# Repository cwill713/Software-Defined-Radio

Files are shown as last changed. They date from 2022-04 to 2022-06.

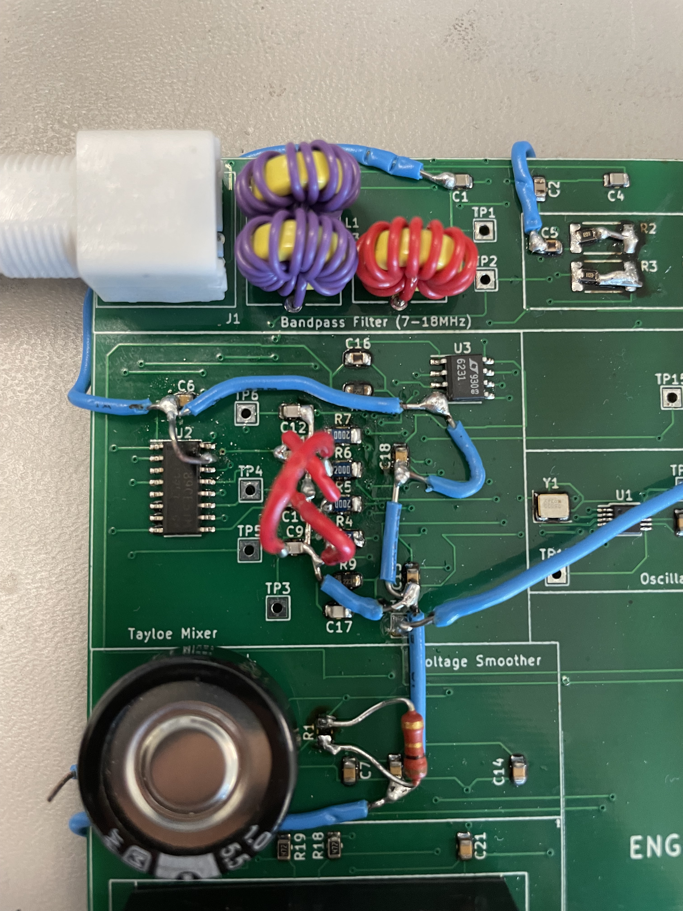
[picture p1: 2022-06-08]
Pictures/Josh's Fixed Board image 2.jpg

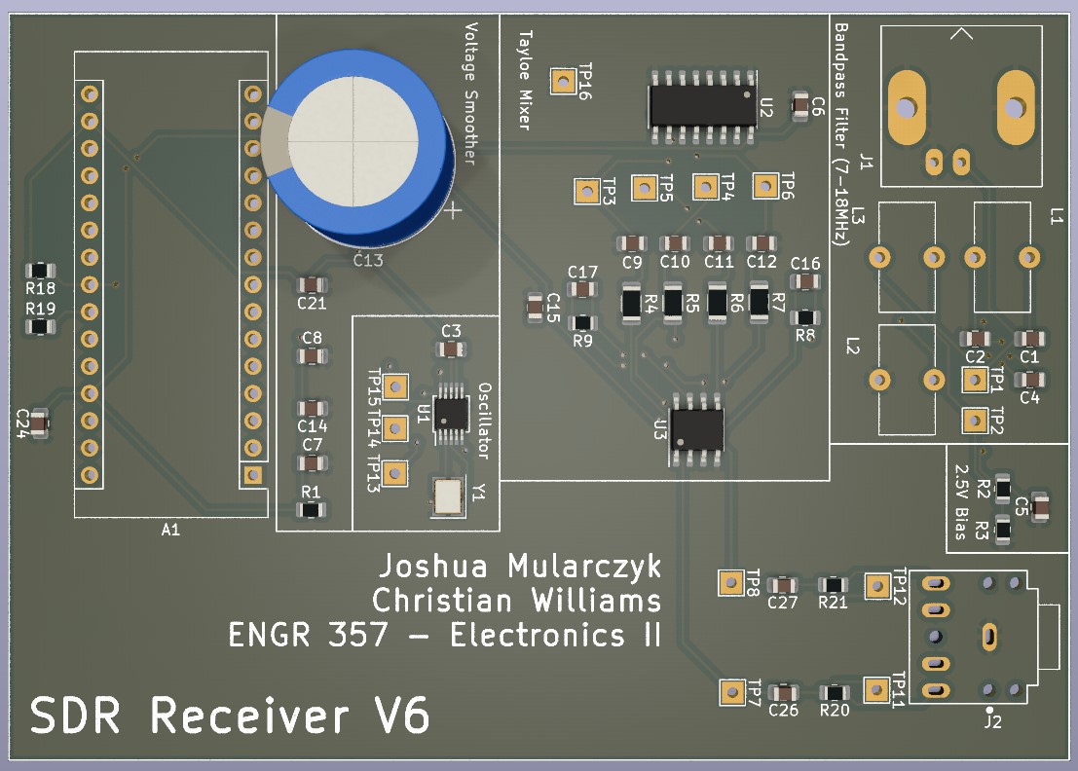
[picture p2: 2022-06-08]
Pictures/V6 Circuit Board.jpg

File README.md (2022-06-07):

# Software-Defined-Radio-Reciever
This project, assigned to us by [Dr. Frohne](https://github.com/frohro), combines our professors' interest HAM radio and a practical application of gain, opamp analysis, noise, and AC/DC analysis that we learned in Electronics I. This is the design of Software Defined Radio built in collaboration with [Joshua Mularczyk](https://github.com/JoshuaMularczyk) for our Engineering Electronics II class.

## Design Specifications
When perfroming research for this project, Joshua and I began to figure out what specifations our SDR would follow. Origianlly, we wanted to build a commercial FM radio, but after discusstion with Dr. Frohne, we reconsidered. The final specifications we decided on are as follows:
- Frequency Range: 7MHZ - 18MHz
- Radio Type: Shortwave
- Inexpensive
- Low Noise Figure
- -107 dBm (1uV) Minimum Discernable Signal
- Good Image Rejection

The subcirucits used to create this SDR are: 
- Butterworth Bandpass Filter
- Tayloe Mixer
- Bessel Lowpass Filter
- Power Supply Noise Filter
- 2.5V Voltage Bias
- Arduino Controlled Oscillator

## Theory



This block diagram shows an overveir of how a Software Defined Radio works. A signal is recieved from the antenna and then passes through the band pass filter. Here all desired frequencies are let through and the others discarded. Then the signals are passed through the Tayloe Mmixer where the signal is then split into four new ones that are 90 degrees out of phase. The these signals, the sets that are 180 degrees apart, are combined in a set of opamps that double as lowpass filters to ensure the output signal has a frequency no greater than 100kHz. These new two signals are then passed through the sound card to the system running the [Quisk](https://james.ahlstrom.name/quisk/) software which allows us to hear what is being transmitted on the signal and change the signal taht we are listening to. The Arduino Nano and the Si5351 that runs a [program](https://github.com/cwill713/Software-Defined-Radio/tree/main/Arduino%20Code/New_Quisk_Nano) that allows it to act as our oscillator that can be changed by what ever frequency Quisk is trying to demodulate.

## Schematics
The following are the initial schematics that Joshua and I have designed for the SDR.

### BandPass Filter
BandPass Filter and Voltage Divider
We built this bandpass filter using the [LC Filter Design Tool](https://rf-tools.com/lc-filter/). This is a Butterworth Filter that will only allow frequencies between 8MHz and 18MHz to pass through it.

The voltage divider will take our Filtered 5V and output a 2.5 DC voltage to drive the rest of the circuit. 

### Mixer and Lowpass Filter
Tayloe Mixer
The mixer that Joshua and I decided to use was  Tayloe Mixer. The Tayloe mixer uses switches to combined the signals that are 180 degrees out of phase with differential amplifiers so that signals above and below the oscilator frequecy can be detected.

The lowpass filter will block all frequencies greater that 100kHz.

### Voltage Smoother
Voltage Smoother

The Voltage Smoother with take the 5V Vcc and remove as much noise as possible that comes in from the computer and outputs a smoother 5V for the SDR to use.

### Arduino and Si5351
Arduino and Si5351

The Si5351 programmable oscillator will allow us to input two clock signals that are 90 degrees out of phase into S0 and S1 of the SN74CBT3253. The Arduino Nano will control the frequency the is put out by the Si5351 for tuning.

## Simulations
The following are the simulations of our filters and our SDR as a whole.

### Bandpass Filter
Bandpass Filter Simulation Graph
Bandpass Filter Simulation

As seen above, the bandpass fitler we designed, as a start band of 7MHz and a stop band of 18MHz.

### Lowpass Filter
LowPass Filter Simulation
LowPass Filter Schematic
After the the I and Q signals from the 2N74CBT3253 are combined in the LT6231 opamps we can see that no frequencies above 100kHz are allowed through.

### Complete SDR
Complete Simulation Graph
Complete SDR Simulation

We simulated our complete SDR the combined bandpass simulation, our tayloe mixer, simulated by using four voltage controlled switches the produced 4 pusles that are 90 degrees out of phase, and our lowpass filter simulation. You can see the two outputs are the baseband I and Q output signals that are 90 degrees out of phase.

## Rev 5 PCB Design and Testing
My partner and I each designed our own version of our board, but my partner had the better board layout. So we used his [V5](https://github.com/cwill713/Software-Defined-Radio/tree/main/Schematic%20Files/SDRrecV5) of our schematic, PCB, and drill files and sent them to our professor who sent our files to [JLPCB](https://jlcpcb.com/VGS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) for printing. We then ordered that parts needed then constructed and tested our board. 

Our V5 Circuit Board PCB

### Initial Testing
During the initial testing, a fellow student, [Nicholas Zimmerman](https://github.com/nickz12345), found that we had a wiring issue in our mixer. To fix this issue on my board, I cut the traces on my board and corrected the mistakes with jumper wires. Jumping one of these traces, I made a mistake and broked one of the capacitors, its pad, and the trace to one of the test points. Due to the lack of time to complete the project, Josh and I used his board for our final testing.

We also found that our boards were missing our ground plan, due to it being temporarily turned off when the gerber files were generated. To fix this I manually wired all the grounds to the ground on the BNC connector.

The last mistake we had was in the second lowpass filter. When had the the second set of opamps running between Vcc and ground instead of Vcc and -Vcc. Because of this, this set of opamps had enough gain that they became saturated. Luckily for us, this second lowpass filter was a back up for the first. We decided to bypass the second lowpass filter because the output signal from the first lowpass filter was exactly what we needed.

The images of our boards can be seen [here](https://github.com/cwill713/Software-Defined-Radio/tree/main/Pictures).

### V6 PCB Design
V6 Circuit Board
After fixing these mistakes on the board, I fixed these issues in the [V6](https://github.com/cwill713/Software-Defined-Radio/tree/main/Schematic%20Files/SDRrecV6) KiCAD files.

## Project Resuslts
### Minimum Discenable Signal
When testing to see the minimum discernible signal we connected our board up to our signal generator, our system running quisk software, and our soundcard. We adjusted the attenuator on the signal generator to output a signal of 14.19MHz and adjusted the attenuator to see how small of a signal we could detect. In the image below, we see our radio discern a signal of .35uV!
minDecV2

### Practical Test
Next, we decided to see if we could find any bandwidths where people were talking and try to listen in. To do this, we disconnected the board from the signal generator and connected our board to the antenna of our building. Scanning the differnt frequencies we found two bandwidths being used for communications.

The first was being used to communicate the weather from what we are assuming to be an air traffic control tower. 

weather
"Wind 360 degrees, light drizzle, visibility more than 6 miles".

The second bandwidth was being used as an automated message that repeated the time once a minute.
listeningIn
"At the tone ***** _5 hours 52 minutes coordinated universal time"

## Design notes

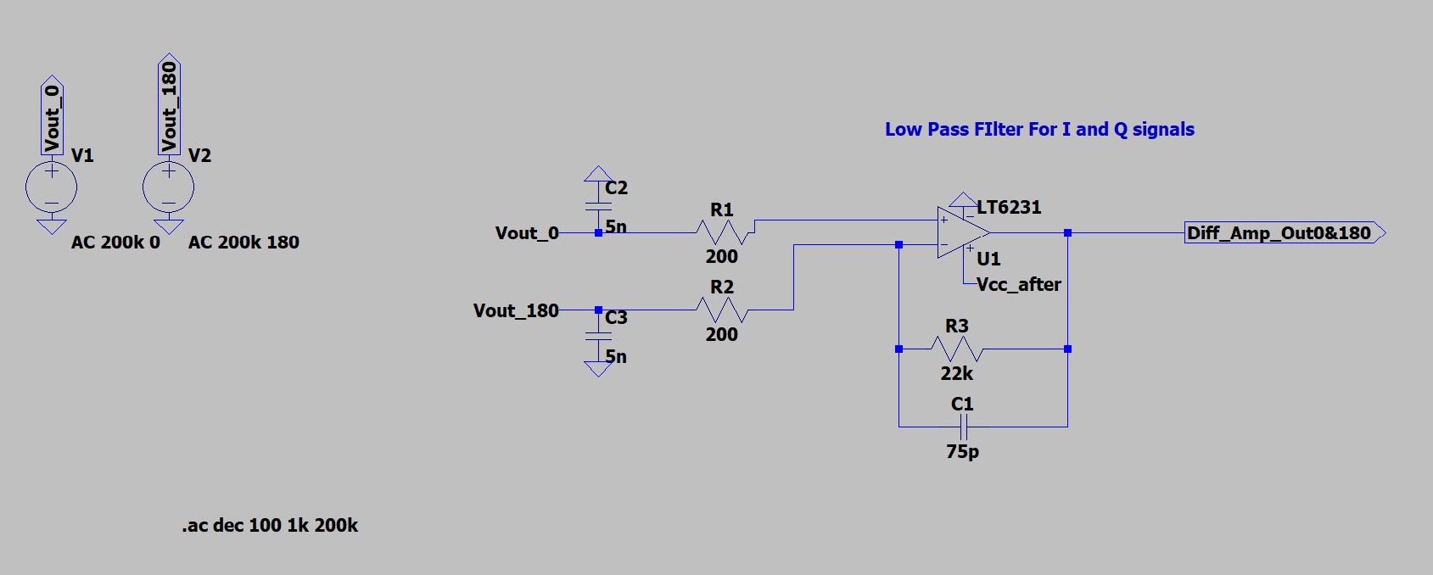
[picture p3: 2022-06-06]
Pictures/LowPass Filter Schematic.jpg

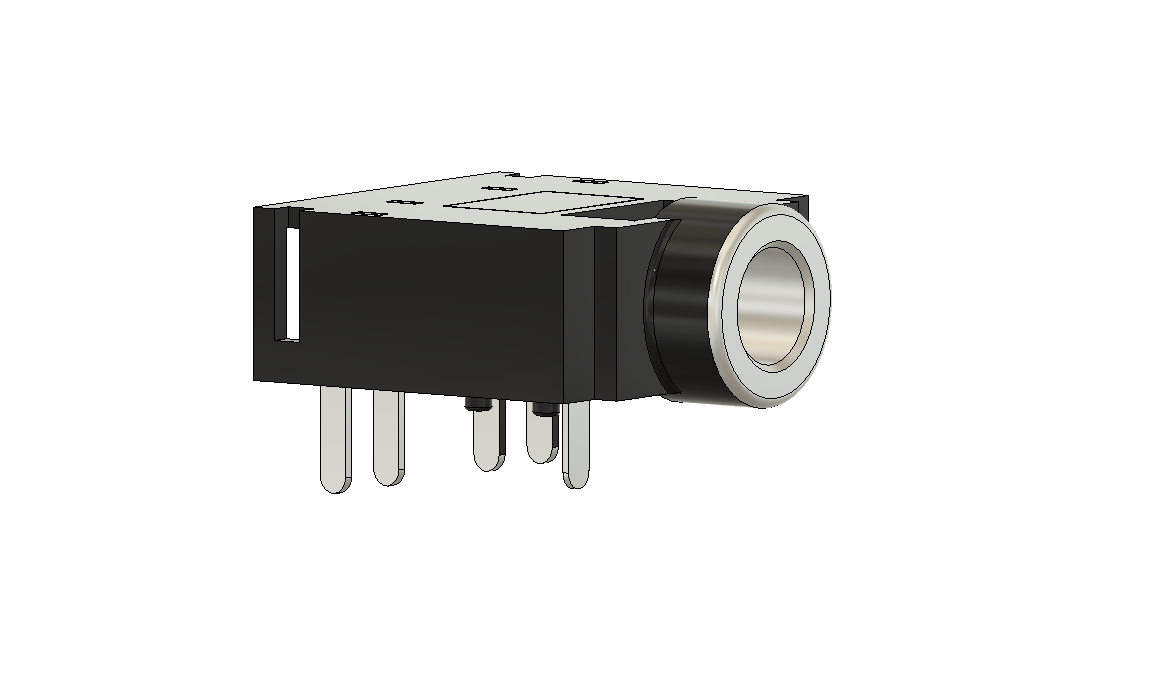
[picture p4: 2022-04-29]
Schematic Files/Audio Jack_Stereo 3.5mm/Audio_Jack2.png

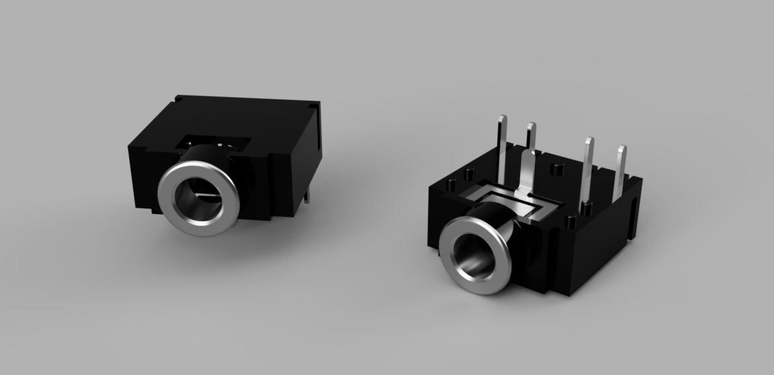
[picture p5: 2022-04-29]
Schematic Files/Audio Jack_Stereo 3.5mm/Audio_Jack1.png

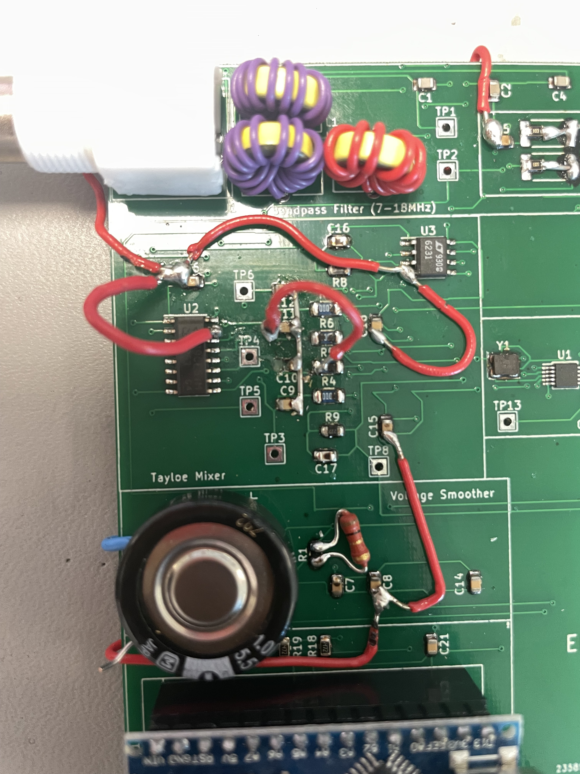
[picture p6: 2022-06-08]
Pictures/Broken Trace, Pad and Capacitor on Christian's Board.jpg

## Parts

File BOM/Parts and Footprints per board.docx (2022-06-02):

Parts and Footprints per board

2 10k Ohm resistor https://www.digikey.com/en/products/detail/cal-chip-electronics-inc/RM25J103CT/13569104 | 2512 packaging
2 270pF Capacitors https://www.digikey.com/en/products/detail/panasonic-electronic-components/ECH-U1H271GX5/353662 | Capacitor_SMD:C_0805_2012Metric
2 750nH Inductor https://www.digikey.com/en/products/detail/te-connectivity-passive-product/36502AR75JTDG/5399630 | 0805 packaging
1 560pF Capacitor https://www.digikey.com/en/products/detail/panasonic-electronic-components/ECH-U1H561GX5/353666 | Capacitor_SMD:C_0805_2012Metric
1 360nH Inductor https://www.digikey.com/en/products/detail/te-connectivity-passive-product/36502AR36JTDG/5399627 | 0805 packaging
9 .1uF Capacitors https://www.digikey.com/en/products/detail/cornell-dubilier-electronics-cde/FCA0805C104M-J2/1924083 | Capacitor_SMD:C_0805_2012Metric
1 SN74CBT3253D https://www.digikey.com/en/products/detail/texas-instruments/SN74CBT3253D/377929 | SOIC-16_3.9x9.9mm
4 5n Capacitors https://www.digikey.com/en/products/detail/murata-electronics/GRM2195C1H512JA01D/586786 | Capacitor_SMD:C_0805_2012Metric
4 200 Ohm Resistors https://www.digikey.com/en/products/detail/koa-speer-electronics-inc/RK73G2BTTD2000D/13590332 | Resistor_SMD:R_1206_3216Metric
2 22k Ohm Resistor https://www.digikey.com/en/products/detail/te-connectivity-passive-product/CRG0805F22K/2380871 | Resistor_SMD:R_0805_2012Metric
2 75pf Capacitors https://www.mouser.com/ProductDetail/Kyocera-AVX/08055A750FAT2A?qs=PcWMbIuZCschK4TeXNjJGQ%3D%3D | Capacitor_SMD:C_0805_2012Metric
2 4.64k Resistors https://www.digikey.com/en/products/detail/panasonic-electronic-components/ERJ-6ENF4641V/93079 | 0805
2 52.3k Resistors https://www.digikey.com/en/products/detail/stackpole-electronics-inc/RNCP0805FTD52K3/2240287 | Resistor_SMD:R_0805_2012Metric
4 100 pf Capacitors https://www.digikey.com/en/products/detail/panasonic-electronic-components/ECH-U1H101GX5/353657 | Capacitor_SMD:C_0805_2012Metric
2 2.49k Ohm Resistors https://www.digikey.com/en/products/detail/koa-speer-electronics-inc/RK73G2ATTD2491F/13575866 | Resistor_SMD:R_0805_2012Metric
2 17.4k Ohm Resistors https://www.digikey.com/en/products/detail/panasonic-electronic-components/ERA-6AEB1742V/2025773 | Resistor_SMD:R_0603_1608Metric
2 10uF Capacitors https://www.digikey.com/en/products/detail/samsung-electro-mechanics/CL21A106KOQNNNG/3894417 | Capacitor_SMD:C_0805_2012Metric
2 100 Ohm Resistors https://www.digikey.com/en/products/detail/koa-speer-electronics-inc/RK73G2ATTD1000D/13576043 | Resistor_SMD:R_0805_2012Metric
2 4.7k Ohm Resistors https://www.digikey.com/en/products/detail/te-connectivity-passive-product/CRGCQ0805J4K7/8576740 | Resistor_SMD:R_0805_2012Metric
1 10nF Capacitor https://www.digikey.com/en/products/detail/cornell-dubilier-electronics-cde/FCP0805C103J-J2/1924307 | Capacitor_SMD:C_0805_2012Metric
1 100nF Capacitor https://www.digikey.com/en/products/detail/cornell-dubilier-electronics-cde/FCA0805C104M-J2/1924083 | Capacitor_SMD:C_0805_2012Metric
1 10uF Polarized Capacitor https://www.digikey.com/en/products/detail/panasonic-electronic-components/EEE-FK1C100R/765952 | lmao:CAP_EEEFK1C100R
1 25MHz Crystal https://www.digikey.com/en/products/detail/kyocera-avx/CX3225SB25000D0FLJCC/6123311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 | Crystal:Crystal_SMD_3225-4Pin_3.2x2.5mm

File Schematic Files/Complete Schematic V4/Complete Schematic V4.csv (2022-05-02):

Source: | C:\Users\willi\OneDrive\Documents\Walla Walla University\Spring 2022\Electronics II\SDR GitHub\Schematic\Complete Schematic V4\Complete Schematic V4.kicad_sch
Date: | 4/28/2022 12:24:08 AM
Tool: | Eeschema (6.0.4)
Generator: | C:\Program Files\KiCad\6.0\bin\scripting\plugins/bom_csv_grouped_by_value_with_fp.py
Component Count: | 73
Ref | Qnty | Value | Cmp name | Footprint | Description | Vendor
A1, | 1 | Arduino_Nano_v3.x | Arduino_Nano_v3.x | Module:Arduino_Nano | Arduino Nano v3.x
C1, C4, | 2 | 270p | C | Capacitor_SMD:C_0805_2012Metric | Unpolarized capacitor
C2, | 1 | 560p | C | Capacitor_SMD:C_0805_2012Metric | Unpolarized capacitor
C3, C5, C6, C14, C15, C18, C21, C24, C25, | 9 | 0.1u | C | Capacitor_SMD:C_0805_2012Metric | Unpolarized capacitor
C7, | 1 | 10n | C | Capacitor_SMD:C_0805_2012Metric | Unpolarized capacitor
C8, | 1 | 100n | C | Capacitor_SMD:C_0805_2012Metric | Unpolarized capacitor
C9, C10, C11, C12, | 4 | 5n | C | Capacitor_SMD:C_0805_2012Metric | Unpolarized capacitor
C13, | 1 | EEEFK1C100R | EEEFK1C100R | lmao:CAP_EEEFK1C100R
C16, C17, | 2 | 75p | C | Capacitor_SMD:C_0805_2012Metric | Unpolarized capacitor
C19, C20, C22, C23, | 4 | 100p | C | Capacitor_SMD:C_0805_2012Metric | Unpolarized capacitor
C26, C27, | 2 | 10u | C | Capacitor_SMD:C_0805_2012Metric | Unpolarized capacitor
J1, | 1 | Conn_Coaxial | Conn_Coaxial | Connector_Coaxial:BNC_Amphenol_B6252HB-NPP3G-50_Horizontal | coaxial connector (BNC, SMA, SMB, SMC, Cinch/RCA, LEMO, ...)
J2, | 1 | USB_A | USB_A | Connector_USB:USB_A_Molex_67643_Horizontal | USB Type A connector
J3, | 1 | AudioJack3 | AudioJack3 | Connector_Audio:Jack_3.5mm_CUI_SJ-3523-SMT_Horizontal | Audio Jack, 3 Poles (Stereo / TRS)
L1, L3, | 2 | 750n | L | Inductor_SMD:L_0805_2012Metric | Inductor
L2, | 1 | 360n | L | Inductor_SMD:L_0805_2012Metric | Inductor
R2, R3, | 2 | 10k | R | Resistor_SMD:R_2512_6332Metric | Resistor
R4, R5, R6, R7, | 4 | 200 | R | Resistor_SMD:R_1206_3216Metric | Resistor
R8, R9, | 2 | 22k | R | Resistor_SMD:R_2512_6332Metric | Resistor
R10, R11, | 2 | 4.64k | R | Resistor_SMD:R_0805_2012Metric | Resistor
R12, R13, | 2 | 52.3k | R | Resistor_SMD:R_0805_2012Metric | Resistor
R14, R15, | 2 | 2.49k | R | Resistor_SMD:R_0805_2012Metric | Resistor
R16, R17, | 2 | 17.4k | R | Resistor_SMD:R_0805_2012Metric | Resistor
R18, R19, | 2 | 4.7k | R | Resistor_SMD:R_0805_2012Metric | Resistor
R20, R21, | 2 | 100 | R | Resistor_SMD:R_0805_2012Metric | Resistor
TP1, TP2, TP3, TP4, TP5, TP6, TP7, TP8, TP9, TP10, TP11, TP12, | 12 | TestPoint | TestPoint |  | test point
U1, | 1 | Si5351A-B-GT | Si5351A-B-GT | Package_SO:MSOP-10_3x3mm_P0.5mm | I2C Programmable Any-Frequency CMOS Clock Generator, MSOP-8
U2, | 1 | SN74CBT3253 | SN74CBT3253 | Package_SO:SOIC-16_3.9x9.9mm_P1.27mm | Dual 1 to 4 Analog Multiplexer
U3, U4, | 2 | LT6231 | OPAMP | Package_SO:SOIC-8_3.9x4.9mm_P1.27mm | OPAmp symbol for simulation only
U5, U6, | 2 | LM4562MA | OPAMP | Package_SO:SOIC-8_3.9x4.9mm_P1.27mm | OPAmp symbol for simulation only
Y1, | 1 | Crystal | Crystal |  | Two pin crystal

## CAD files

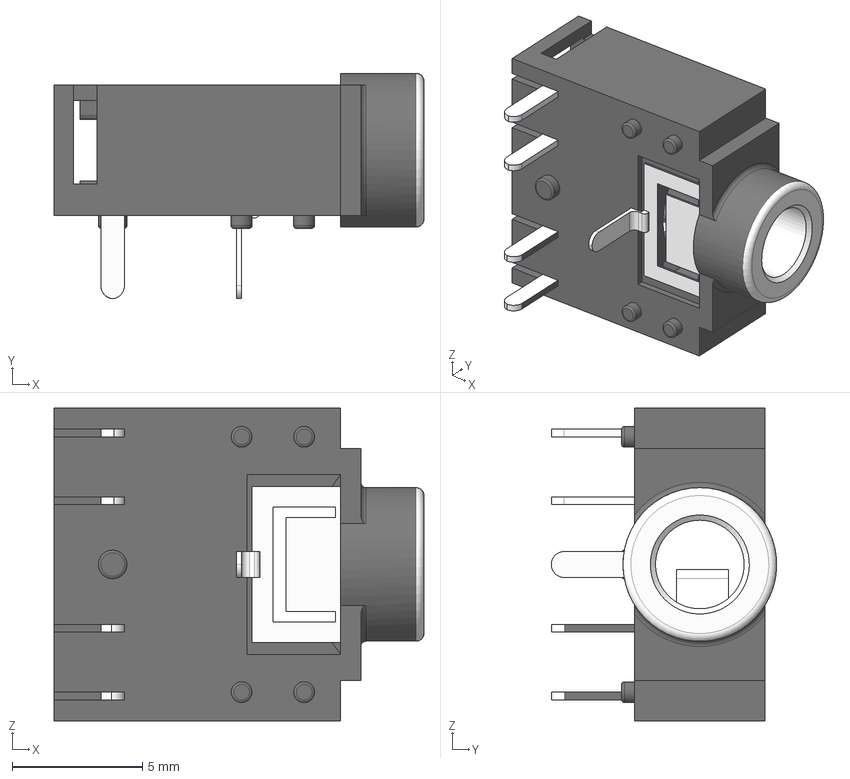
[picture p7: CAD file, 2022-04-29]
Schematic Files/Audio Jack_Stereo 3.5mm/Audio Jack.step
14.2 x 8.65 x 12.0 mm

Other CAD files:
Schematic Files/Audio Jack_Stereo 3.5mm/Audio Jack.f3d

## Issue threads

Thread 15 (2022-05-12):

Taloe Mixer MUX SN74CBT3253 needs I/O explanation

nickz12345, 2022-05-12:
**Request**
Please clarify Taloe mixer operation and document sampling phase angles 0°, 90°, 180°, and 270°.
See screenshot from your SDRrecV5 schematic:
 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

**Theory**
Quadrature sampling takes 0° and 90° outputs and amplifies them. See picture:
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

Waveforms cos(x-180°) and cos(x-270°) are negative amplitude of waveforms cos(x-0°) and cos(x-90°) at the sampling frequency, so the amplified difference of the (cos(x-0°)-cos(x-180°)), and (cos(x-90°)-cos(x-270°)) effectively amplify 2cos(x-0°) and 2cos(x-90°).

**Potential Issue**
Outputs coming out the the SN74CBT3253 Taloe mixer MUX are wired to the op-amps incorrectly if 1B1, 1B2, 1B3, and 1B4 are to be interpreted as 0°, 90°, 180°, and 270° respectively, and the same applies to the parallel duplicate outputs 2B1, 2B2, 2B3, and 2B4. This phase assumption might be valid for gray code clock inputs to the SN74CBT3253 MUX.  Under the assumption that your mixer outputs 1B1, 1B2, 1B3, and 1B4 are to be interpreted as 0°, 90°, 180°, and 270° respectively, then the top difference amplifier is amplifying the signal at (cos(x-0°)-cos(x-90°)) and (cos(x-180°)-cos(x-270°)). Under this assumption of 0°, 90°, 180°, and 270° respectively on the 1B1, 1B2, 1B3, and 1B4 outputs, the Taloe mixer will not quadrature sample properly.

**References**
- [http://www.norcalqrp.org/files/Tayloe_mixer_x3a.pdf](url)

References:

frohro, 2022-05-15:
I concur with Nick on this observation.  It is a good one.  I think he has an idea that might fix it in software that is worth trying.

Closed 2023-02-08.

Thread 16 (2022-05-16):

SDA and SCL are 3.3V for the Si5351 and 5V for the Nano

frohro, 2022-05-16:
Hi Guys,
Another issue you might have is that SDA and SCL on the I2C interface are 5V on the Nano and 3.3V on the Si5351.  It usually works, but not always.  You will need pull-ups to 3.3V for sure, but sometimes the Si5351 doesn't send a high enough signal to trigger the Nano.  You can fix this with a FET and a couple of resistors in between the two devices to level shift the signals.  Check to see you have the frequency you need.  You can skip Quisk and just open the serial monitor in the Arduino IDE and set the baud to 57600 and then type FREQ return, and then FREQ,14200000 to change the frequency to 14.2 MHz.  The latest code with the quadrature is in the muSDR branch on github of the IQ-SDR..
Rob

cwill713, 2022-06-03:
When checking

Closed 2022-06-03.

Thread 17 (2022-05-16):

Ground Loops Mediation

frohro, 2022-05-16:
Ground loops can be an issue when connecting to an antenna and PC.  I put jumpers to test for ground loops in my radio, but I don't think you did.  You may be able to try it running on a laptop from a battery and things like that.  Here is a good [article](https://sites.google.com/site/g4zfqradio/configuring-a-softrock-sdr/more-on-ground-loops-and-audio-settings) on ground loop problems with audio SDR's like yours.
Rob

Closed 2023-02-08.

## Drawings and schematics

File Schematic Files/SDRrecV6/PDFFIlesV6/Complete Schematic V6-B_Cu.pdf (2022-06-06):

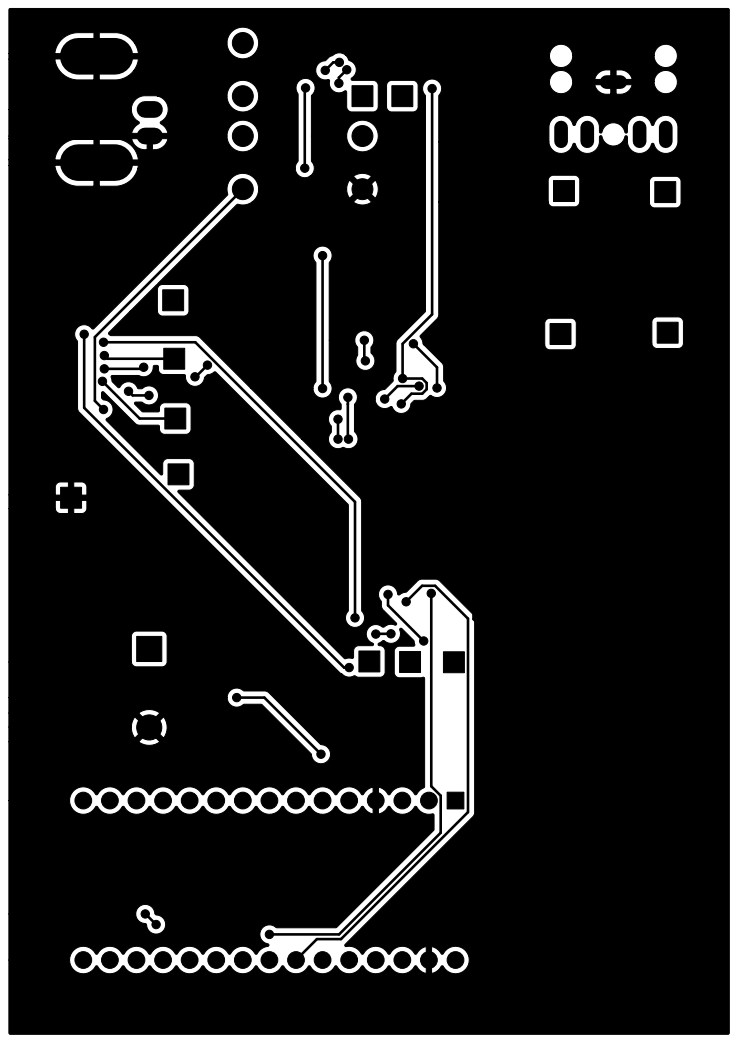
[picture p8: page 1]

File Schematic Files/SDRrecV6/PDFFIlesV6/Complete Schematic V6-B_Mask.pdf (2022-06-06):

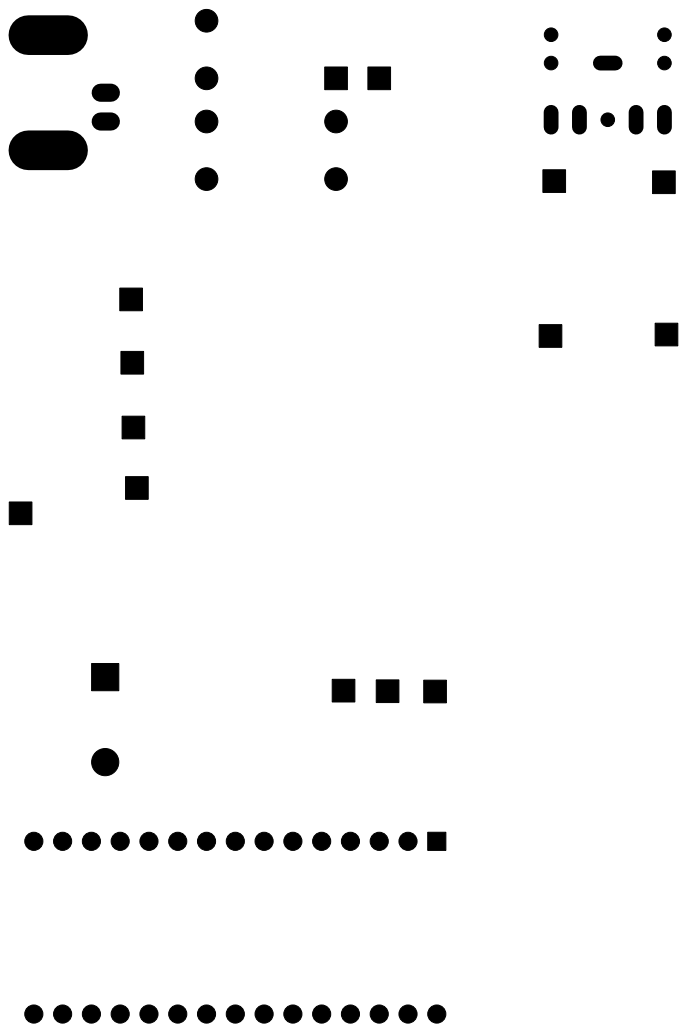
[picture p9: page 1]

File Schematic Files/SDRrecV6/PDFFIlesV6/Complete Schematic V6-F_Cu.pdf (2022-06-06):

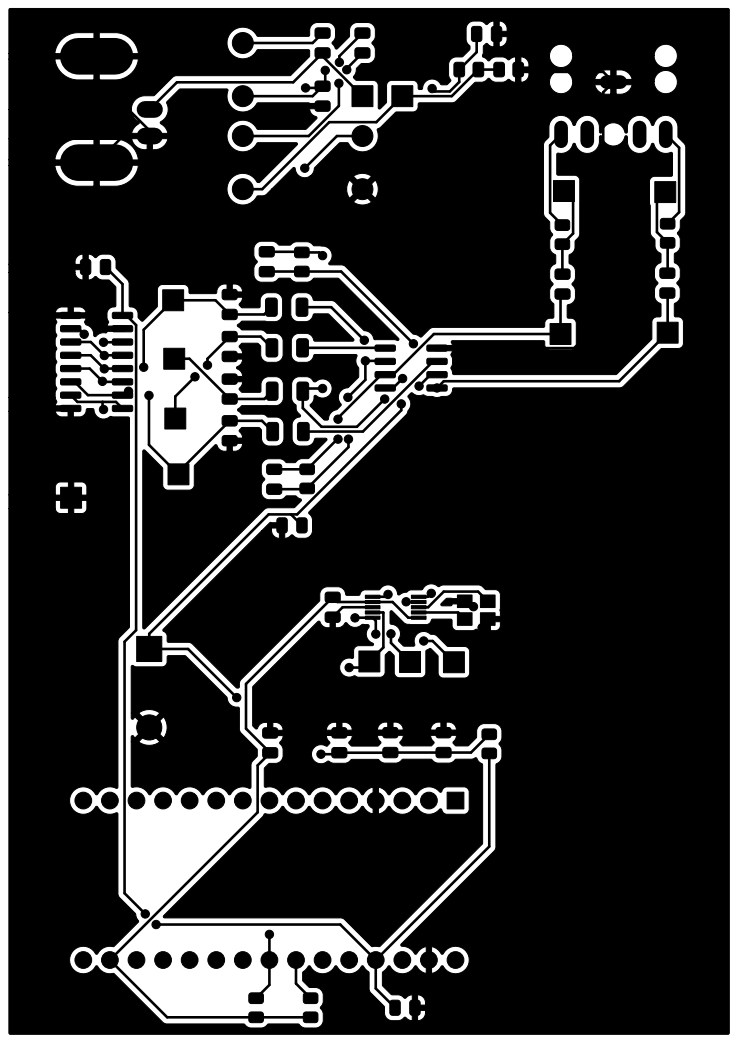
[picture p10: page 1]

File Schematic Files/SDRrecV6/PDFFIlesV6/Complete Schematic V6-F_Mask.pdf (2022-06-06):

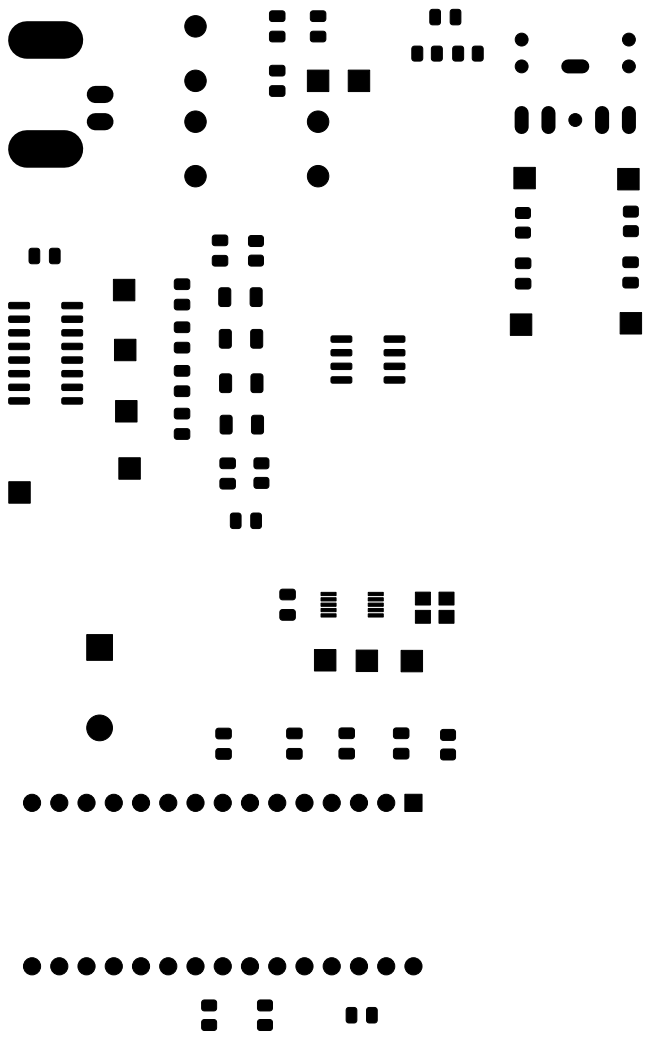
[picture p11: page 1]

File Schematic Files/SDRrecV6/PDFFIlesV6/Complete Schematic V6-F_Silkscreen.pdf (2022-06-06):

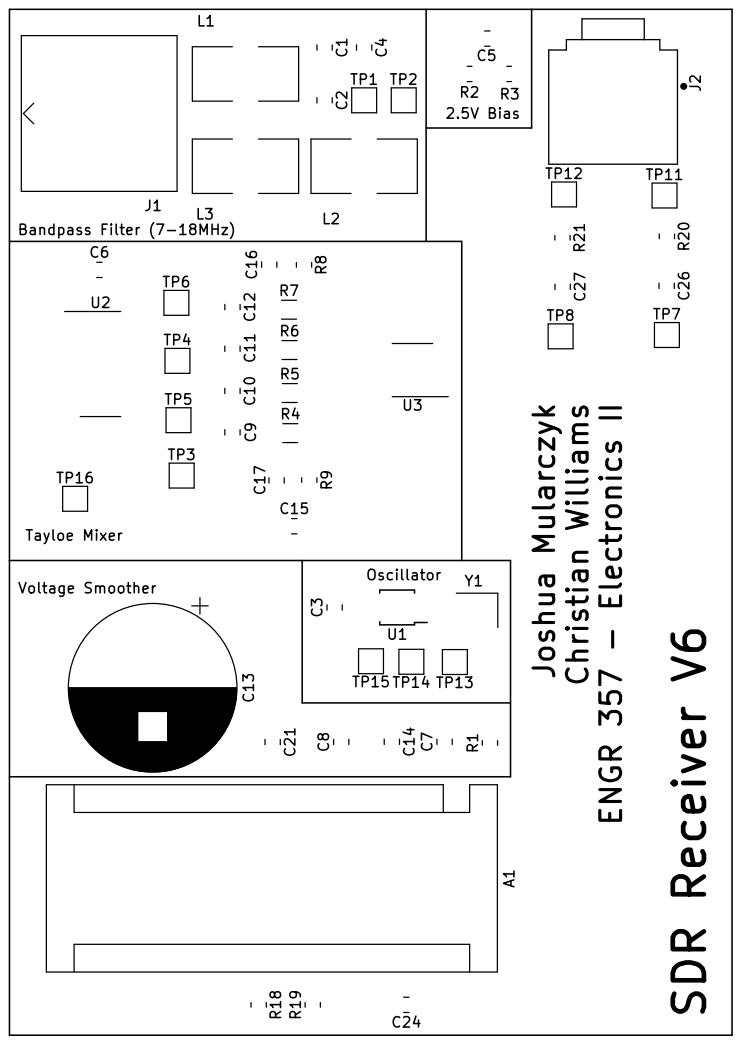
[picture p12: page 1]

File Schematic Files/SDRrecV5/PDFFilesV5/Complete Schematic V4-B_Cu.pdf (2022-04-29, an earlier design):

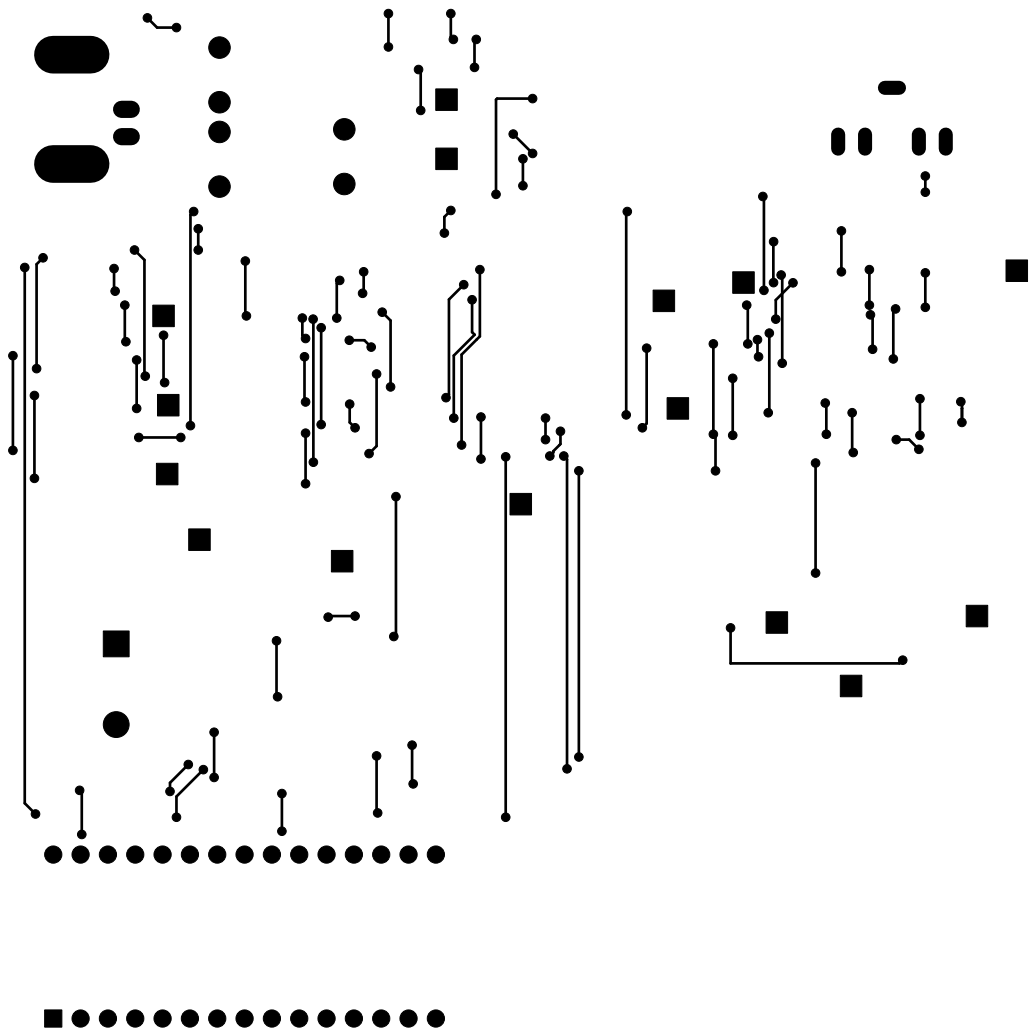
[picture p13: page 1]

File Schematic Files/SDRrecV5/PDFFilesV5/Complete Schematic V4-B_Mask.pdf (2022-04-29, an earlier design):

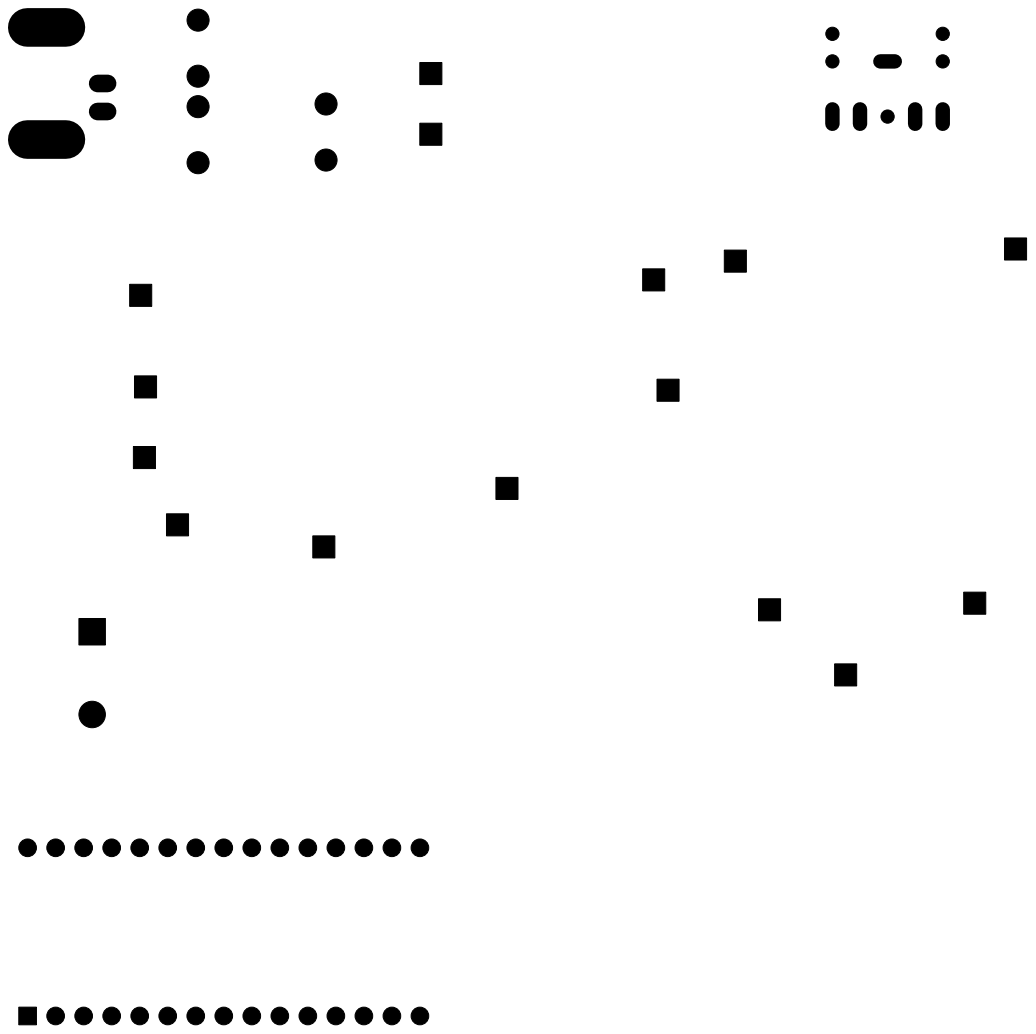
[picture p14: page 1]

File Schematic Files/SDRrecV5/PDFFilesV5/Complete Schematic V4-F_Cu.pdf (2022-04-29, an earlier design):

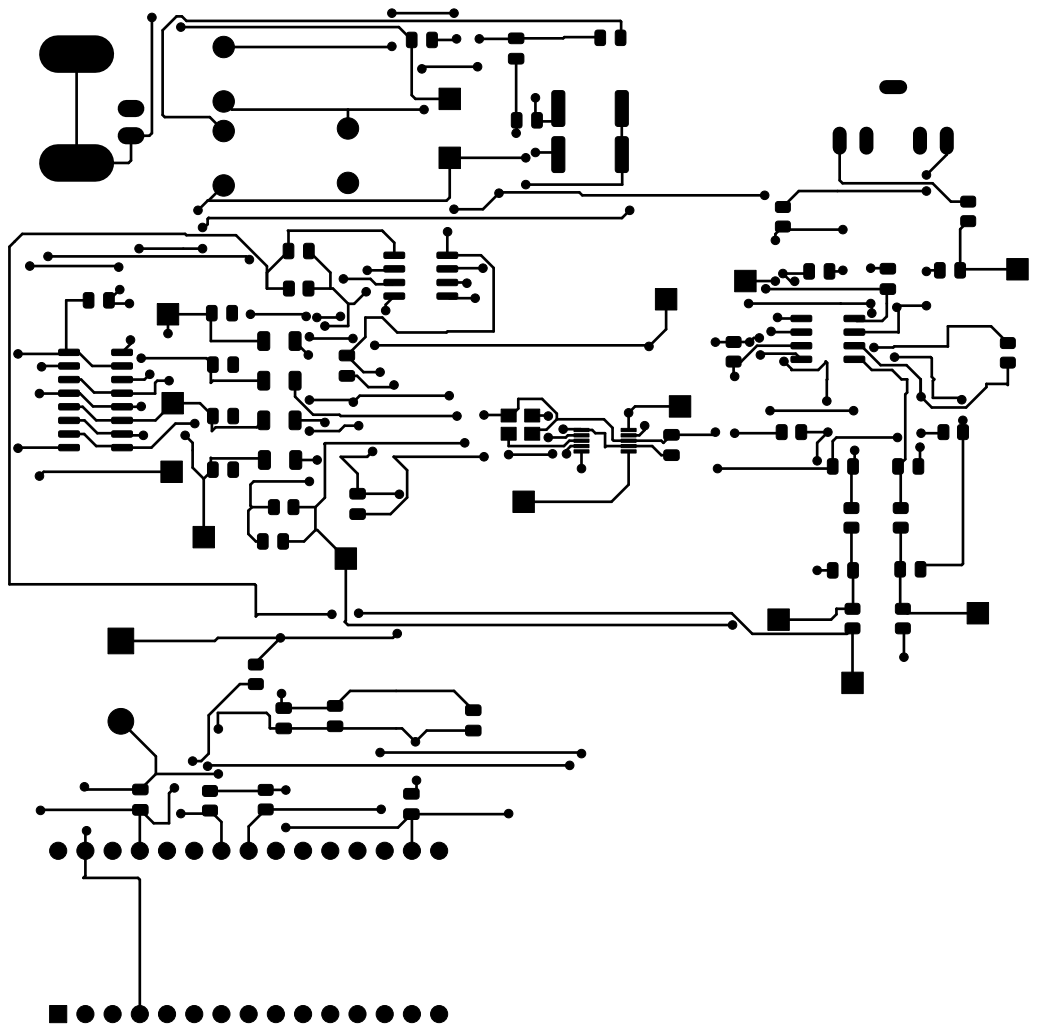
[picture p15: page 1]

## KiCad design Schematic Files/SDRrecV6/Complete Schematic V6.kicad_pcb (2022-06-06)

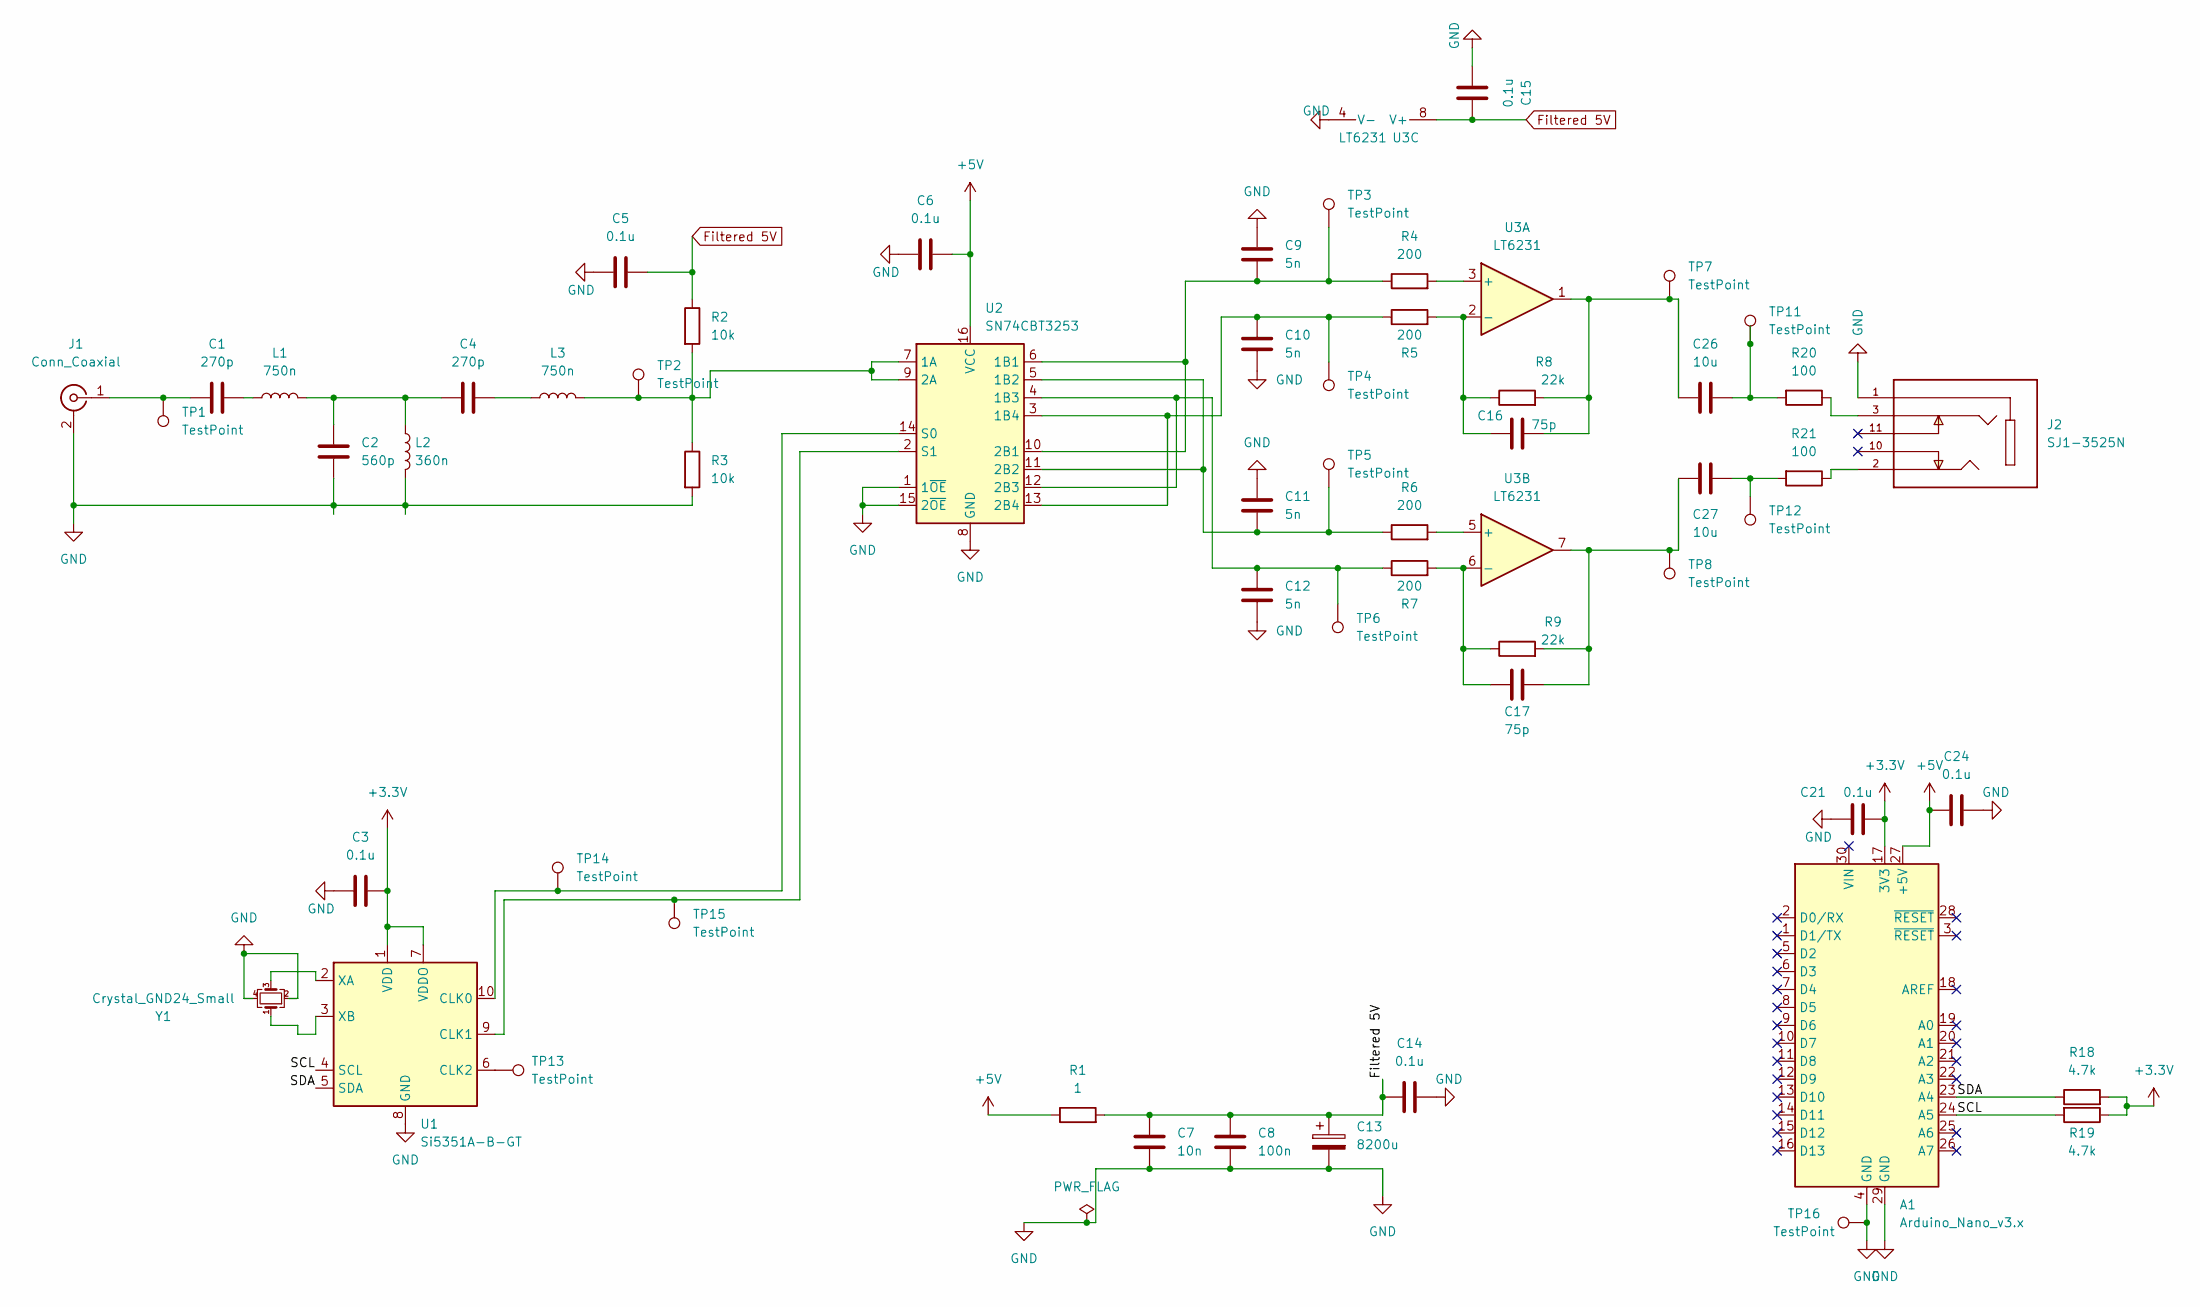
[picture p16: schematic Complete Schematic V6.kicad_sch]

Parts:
A1: Arduino_Nano_v3.x; Arduino_Nano
C1, C4: 270p; C_0805_2012Metric
C2: 560p; C_0805_2012Metric
C3, C5, C6, C14, C15, C21, C24: 0.1u; C_0805_2012Metric
C7: 10n; C_0805_2012Metric
C8: 100n; C_0805_2012Metric
C9, C10, C11, C12: 5n; C_0805_2012Metric
C13: 8200u; CP_Radial_D16.0mm_P7.50mm
C16, C17: 75p; C_0805_2012Metric
C26, C27: 10u; C_0805_2012Metric
J1: Conn_Coaxial; BNC_Amphenol_B6252HB-NPP3G-50_Horizontal
J2: SJ1-3525N; PARTREV 1.02
L1, L3: 750n; L_Toroid_Vertical_L10.0mm_W5.0mm_P5.08mm
L2: 360n; L_Toroid_Vertical_L10.0mm_W5.0mm_P5.08mm
R1: 1; R_0805_2012Metric
R2, R3: 10k; R_0805_2012Metric
R4, R5, R6, R7: 200; R_1206_3216Metric
R8, R9: 22k; R_0805_2012Metric
R18, R19: 4.7k; R_0805_2012Metric
R20, R21: 100; R_0805_2012Metric
TP1, TP2, TP3, TP4, TP5, TP6, TP7, TP8, TP11, TP12, TP13, TP14, TP15, TP16: TestPoint; TestPoint_THTPad_2.0x2.0mm_Drill1.0mm
U1: Si5351A-B-GT; MSOP-10_3x3mm_P0.5mm
U2: SN74CBT3253; SOIC-16_3.9x9.9mm_P1.27mm
U3: LT6231; SOIC-8_3.9x4.9mm_P1.27mm
Y1: Crystal_GND24_Small; Crystal_SMD_3225-4Pin_3.2x2.5mm

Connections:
+3V3: A1.17 (3V3), C3.2, C21.2, R18.2, R19.1, U1.1 (VDD), U1.7 (VDDO)
+5V: A1.27 (+5V), C6.2, C24.2, R1.1, U2.16 (VCC)
/SCL: A1.24 (A5), R19.2, U1.4 (SCL)
/SDA: A1.23 (A4), R18.1, U1.5 (SDA)
Filtered 5V: C5.2, C7.1, C8.1, C13.1, C14.2, C15.2, R1.2, R2.1, U3.8 (V+)
GND: A1.4 (GND), A1.29 (GND), C2.2, C3.1, C5.1, C6.1, C7.2, C8.2, C9.2, C10.1, C11.2, C12.1, C13.2, C14.1, C15.1, C21.1, C24.1, J1.2 (Ext), J2.1, L2.2, R3.2, TP16.1, U1.8 (GND), U2.1 (1~OE), U2.8 (GND), U2.15 (2~OE), U3.4 (V-), Y1.2, Y1.4
unnamed: C1.1, L1.1
unnamed: C1.2, J1.1 (In), TP1.1
unnamed: C2.1, C4.1, L1.2, L2.1
unnamed: C4.2, L3.1
unnamed: C9.1, R4.1, TP3.1, U2.6 (1B1), U2.10 (2B1)
unnamed: C10.2, R5.1, TP4.1, U2.3 (1B4), U2.13 (2B4)
unnamed: C11.1, R6.1, TP5.1, U2.5 (1B2), U2.11 (2B2)
unnamed: C12.2, R7.1, TP6.1, U2.4 (1B3), U2.12 (2B3)
unnamed: C16.1, C26.2, R8.2, TP7.1, U3.1
unnamed: C16.2, R5.2, R8.1, U3.2 (-)
unnamed: C17.1, C27.2, R9.2, TP8.1, U3.7
unnamed: C17.2, R7.2, R9.1, U3.6 (-)
unnamed: C26.1, R20.2, TP11.1
unnamed: C27.1, R21.2, TP12.1
unnamed: J2.2, R21.1
unnamed: J2.3, R20.1
unnamed: L3.2, R2.2, R3.1, TP2.1, U2.7 (1A), U2.9 (2A)
unnamed: R4.2, U3.3 (+)
unnamed: R6.2, U3.5 (+)
unnamed: TP13.1, U1.6 (CLK2)
unnamed: TP14.1, U1.10 (CLK0), U2.14 (S0)
unnamed: TP15.1, U1.9 (CLK1), U2.2 (S1)
unnamed: U1.2 (XA), Y1.3
unnamed: U1.3 (XB), Y1.1

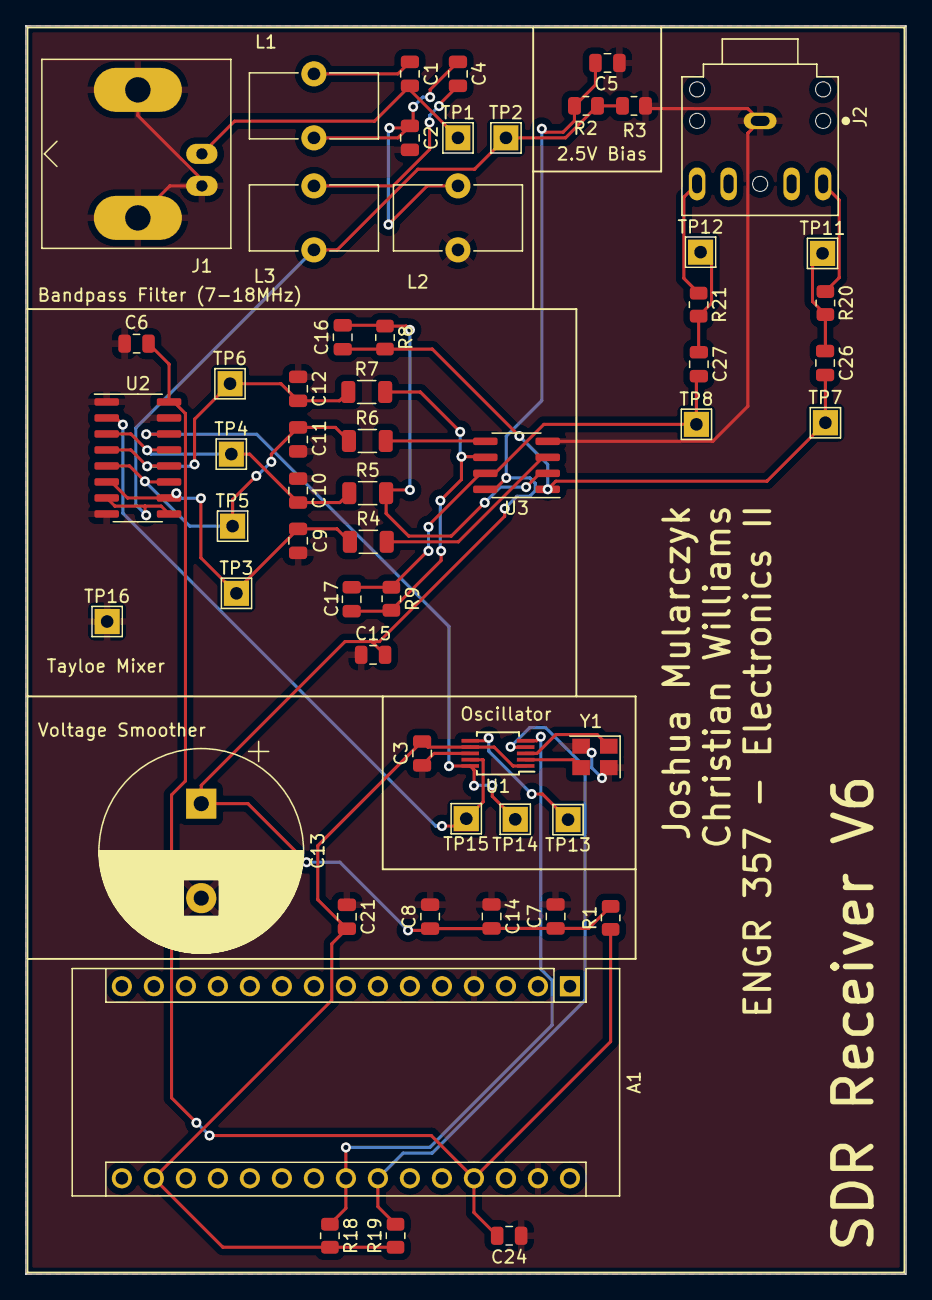
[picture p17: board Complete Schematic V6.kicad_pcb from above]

Board: 2 copper layers, 69.9 x 99.1 mm, 58 parts (0 on the bottom side), 30 nets.

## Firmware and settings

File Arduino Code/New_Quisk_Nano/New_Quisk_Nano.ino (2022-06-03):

#include <si5351.h>

#include <si5351.h>


/*
  OpenRadio Quisk Interface 
  Main
  This is used to provide a serial interface which Quisk SDR can talk to.
  
  Copyright (C) 2014 Mark Jessop <vk5qi@rfhead.net>

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
    For a full copy of the GNU General Public License, 
    see <http://www.gnu.org/licenses/>.

   Command Reference:
    ------------------
    All commands consist of an identifier, followed by one or more parameters delinieated by commas, then a newline.
    i.e.:
    COMMAND,<param1>,<param2><LF>
    
    A command will return OK<LF> if successful, and ERROR<LF> if not. Some commands (particuarly transmit commands)
    may take a significant amount of time to return.
    
    Sending a command which takes parameters, without sending the parameters, will return the set parameters.
    
    Frequency Settings:
    
    FREQ,<freq>     - Set the center freq of the receiver, in Hz.
    FREQPSK,<freq>    - Set the transmit frequency, in Hz.

    Modulation:
    All transmissions will time out after 10 minutes. (if we implement it)
    
    CARRIER,<ON/OFF>  - Transmit a carrier.
    PSK,<rate>,message  - Send message using Phase Shift Keying, with the specified symbol rate.

    This version is made for the Rasbperry Pi Pico using the MBED OS..
*/

#include <Arduino.h>

//#warning __PGMSPACE_H_

//#include <EEPROM.h>
#include <Wire.h>

#include "si5351.h"

#include "settings.h"
#include "pins.h"
//#include "ring_buffer.h"

#define VERSION "0.3"

// #define USE_JOHNSON_COUNTER
// Default output frequency
#define RX_FREQ 14200000
#define TX_FREQ 14200000
#define FREQ_LIMIT_LOWER 100000
#define FREQ_LIMIT_UPPER 30000000 

#define SERIAL_BAUD     57600

Si5351 si5351;

uint8_t si5351_init();
int parseFreq(String input);
int parseCarrier(String carrier_str);
int set_channel(String input);

int tx_relay_state = 0;
int tx_state = 0;

static struct settings settings;

// Ring buffer for use with the interrupt-driven transmit buffer.
//struct ring_buffer data_tx_buffer = { { 0 }, 0, 0};

/* Returns true if settings are valid */
//static bool read_settings(void)
//{
//    uint8_t *p = (uint8_t *)&settings;
//    int i = 0;
//
//    while(i < sizeof(struct settings))
//        *p++ = EEPROM.read(i++);
//
//    return settings.magic == SETTINGS_MAGIC;
//}

//static void write_settings(void)
//{
//    uint8_t *p = (uint8_t *)&settings;
//    int i = 0;
//
//    // Invalidate checksum to guard against partial writes
//    EEPROM.write(0, 0);
//
//    while(i < sizeof(struct settings))
//        EEPROM.write(i++, *p++);
//}

// Input buffer for reading user input.
#define INPUTBUFLEN 64
//char inputBuffer[INPUTBUFLEN];
int inputBufferPtr = 0;
char tempBuffer[20]; // Buffer for string to int conversion.
String inputBuffer = "";

void setup(){
    // Initialise things.
    pinMode(TX_RX_SWITCH, OUTPUT);
    digitalWrite(TX_RX_SWITCH, LOW);
    pinMode(MODULATION, OUTPUT);
    digitalWrite(MODULATION, LOW);
    pinMode(LED, OUTPUT);
    digitalWrite(LED, LOW);

    Serial.begin(SERIAL_BAUD);
    Serial.setTimeout(1000 * 10);

    uint8_t rev_id = si5351_init();

    // Click the relay as an 'audible' startup indicator.
    digitalWrite(TX_RX_SWITCH, HIGH);
    delay(300);
    digitalWrite(TX_RX_SWITCH, LOW);



// Perform Si5351 calibration
    uint64_t rx_freq = 1000024200ULL;  // Where you receive WWV before calibration...
    uint64_t target_freq = 1000000000ULL; // 10 MHz, in hundredths of hertz
    uint32_t cal_factor = (int32_t)(target_freq - rx_freq);
    si5351.set_correction(cal_factor, SI5351_PLL_INPUT_XO);
    si5351.set_pll(SI5351_PLL_FIXED, SI5351_PLLA);
    si5351.pll_reset(SI5351_PLLA);

   //    if (!read_settings()) {
        //Serial.println(F("Resetting settings to defaults"));
        settings.magic = SETTINGS_MAGIC;
        settings.rx_freq = RX_FREQ;
        settings.tx_freq = TX_FREQ;
        settings.cal_factor = cal_factor;
//    }
    
    set_rx_freq(settings.rx_freq);
    set_tx_freq(settings.tx_freq);
}

void loop(){
  if(Serial.available()){
    // Read in a byte.
    char inChar = (char)Serial.read();
    
    // Work out what the character is. If letters or numbers, add to
    // the buffer, if not, don't add.
    
    // If character is a newline, we have reached the end of the command.
    if( (inChar == '\n') || (inputBufferPtr>INPUTBUFLEN)){
      // Parse string
      if( parseCommand(inputBuffer)==0 ){
        Serial.println("OK");
      }else{
        Serial.println("ERROR");
      }
      inputBuffer = "";
      inputBufferPtr = 0;
    }else if( isalnum(inChar) || ispunct(inChar) || isblank(inChar) || inChar==4 ){
      // Add to the input buffer if printable and not a line ending.
      inputBuffer += inChar;
      inputBufferPtr++;
    }
  }
}

// CSV parser function. Splits input into arguments.
// I am so sorry...
int parseCommand(String input){
  int params = 0;
  
  if(input.length()<3){
    // No command is shorter than 3 characters. Error.
    return 1;
  }
  // At this point we have found some sort of command (maybe)
  

  // Search through for commas, populate an array of pointers, make pointer = -1 if nothing found.
  // NOTE: This is a horrible bit of code. If theres is a better way to do CSV parsing in Arduino, let me know!
  int separators[] = {-1,-1,-1,-1,-1,-1};

  separators[0] = input.indexOf(",");
  
  if(separators[0] != -1){ // If we find one comma, maybe there are more...
    int i = 1;
    while((separators[i-1] != -1) && i<6){
      params++;
      separators[i] = input.indexOf(",", separators[i-1]+1);
      i++;
    }
  
  }

  if(params==0){ // Either a request command or a command with no parameter
    if(input.startsWith("FREQPSK")){
      Serial.print("FREQPSK,"); Serial.println(settings.tx_freq);
      return 0;
    }else 
    if(input.startsWith("FREQ")){
      Serial.print("FREQ,"); Serial.println(settings.rx_freq);
      return 0;
    }else if(input.startsWith("CAL")){
      Serial.print("CAL,"); Serial.println(settings.cal_factor,10);
      return 0;
    }else if(input.startsWith("VER")){
      Serial.print("VER,"); Serial.println("OpenRadio V1.1");
      return 0;
    }else{
      // No other commands are valid without parameters. Error
      return 1;
    }
  }else if(params==1){ // Commands with one argument.
    String param1 = input.substring(separators[0]+1); // Extract the argument for passing to the function.
    if(input.startsWith("FREQPSK")){
//      return parsePSKFreq(param1);
    }else if(input.startsWith("FREQ")){
      return parseFreq(param1);
    }
    else if(input.startsWith("PSKFREQ")){
//      return parsePSKFreq(param1);
    }else if(input.startsWith("CARRIER")){
      return parseCarrier(param1);
    }else if(input.startsWith("CHAN")){
      return set_channel(param1);
    }else{
      // No other commands are valid with only one parameter. Error
      return 1;
    }
  }
//  else if(params==2){ // Commands with 2 parameters (PSK);
//    String param1 = input.substring(separators[0]+1, separators[1]);
//    String param2 = input.substring(separators[1]+1);
//    
//    if(input.startsWith("PSK")){
//      return psk_transmit(param1,param2);
//    }else{
//      // No other commands are valid with only one parameter. Error
//      return 1;
//    }
//  }

  return 1; // Cannot parse command, error.
}

int freqValid(uint32_t freq){
  return (freq>FREQ_LIMIT_LOWER) && (freq<FREQ_LIMIT_UPPER);
}

// Parse frequency, program radio.
int parseFreq(String input){
  unsigned long result = 0;
  unsigned long combinedresult = 0;
  char* endptr;
  
  input.toCharArray(tempBuffer,10);
  
  result = strtoul(tempBuffer,&endptr,10);
  // If strtoul fails to convert, *endptr contains the character which conversion failed on.
  // Otherwise, *endptr contains '\0'.
  if(*endptr != 0) return -1;
  
  if(freqValid(result)){
    set_rx_freq(result);
    Serial.print("FREQ,");Serial.println(result);
    return 0;
  }else{
    //Serial.println("Invalid input.");
    return -1;
  } 
}

// Carrier on/off
// This should transmit a carrier at an offset from the rx freq.
// We probably dont need this right now.
int parseCarrier(String carrier_str){
// TODO
  return -1;
}

// Transit a string of PSK (message) at (rate) baud.
// We need to figure out how to decide what the 'offset' from the RF freq is.
// Maybe add another command to set this?
int parsePSK(String rate, String message){
// TODO
  return -1;
}

// Set the frequency of the transmitted PSK signal.
// This is entirely independent of the receive chain, and we should
// be controlling if we want to lock this to within the RX passband 
// from within the client software.
int parsePSKFreq(String input){
  unsigned long result = 0;
  unsigned long combinedresult = 0;
  char* endptr;
  
  input.toCharArray(tempBuffer,10);
  
  result = strtoul(tempBuffer,&endptr,10);
  // If strtoul fails to convert, *endptr contains the character which conversion failed on.
  // Otherwise, *endptr contains '\0'.
  if(*endptr != 0) return -1;
  
  if(freqValid(result)){
    set_tx_freq(result);
    Serial.print("FREQPSK,");Serial.println(result);
    return 0;
  }else{
    //Serial.println("Invalid input.");
    return -1;
  } 

}


//
// Si5351 Helper Functions
//

uint8_t si5351_init(){
    si5351.init(SI5351_CRYSTAL_LOAD_8PF,0,0);
    si5351.set_pll(SI5351_PLL_FIXED, SI5351_PLLA);
    // Set output frequencies
    set_rx_freq(RX_FREQ);
    set_tx_freq(TX_FREQ);

    // Enable RX, and disable TX by default.
    si5351.output_enable(RX_CLOCK,1);
    si5351.output_enable(TX_CLOCK,0);
    si5351.output_enable(SPARE_CLOCK,0);

    // Read the status register and return the chip revision ID.
    si5351.update_status();
    return si5351.dev_status.REVID;

}

static void set_rx_freq(uint32_t freq)
{
    // Save actual value
    settings.rx_freq = freq;

#ifdef USE_JOHNSON_COUNTER
    // This is for models where quadrature mixer requires a 4X LO signal.
    si5351.set_freq(freq * 4, RX_CLOCK);
#else
 // This is for models that use the Si5351 to produce the I/Q on CLK0 and CLK1.
  uint64_t pll_freq;
  uint_fast8_t mult;
  // mult must be less than 128 (7 bits) according to documentation
  if (freq >= 26470588){
    mult = 22;
  } else if (freq >= 18000000) {
    mult = 34;
  } else if(freq > 12000000) {
    Serial.println("in the right multiplier.");
    mult = 50;
  } else if (freq >= 8000000) {
    mult = 75;
  } else if (freq > 5357143) {
    mult = 112;
  } else {
    mult = 128;
  }
  freq = (uint64_t) (freq*100ULL);
  pll_freq = (uint64_t)mult*freq;
  si5351.set_freq_manual(freq, pll_freq, SI5351_CLK0);
  si5351.set_freq_manual(freq, pll_freq, SI5351_CLK1);
  // Now we can set CLK1 to have a 90 deg phase shift by entering
  // mult in the CLK1 phase register, since the ratio of the PLL to
  // the clock frequency is mult.
  si5351.set_phase(SI5351_CLK0, 0);
  si5351.set_phase(SI5351_CLK1, mult);
  // We need to reset the PLL before they will be in phase alignment
  si5351.pll_reset(SI5351_PLLA);
#endif
if (freq <= 4.0e6){  // Set the band for the RX filters on the IQ_SDR
    digitalWrite(4, HIGH);
    digitalWrite(5, HIGH);
    }
if ((freq <= 8.0e6)&&(freq > 4.0e6)){
    digitalWrite(4, LOW);
    digitalWrite(5, HIGH);
    }
if ((freq <= 16.0e6)&&(freq > 8.0e6)){
    digitalWrite(4, HIGH);
    digitalWrite(5, LOW);
    }
else {
    digitalWrite(4, LOW);
    digitalWrite(5, LOW);
    }       
}

static void set_tx_freq(uint32_t freq)
{
    // Save actual value
    settings.tx_freq = freq;

    // Let driver choose PLL settings. May glitch when changing frequencies.
    si5351.set_freq(freq, (si5351_clock)0);
}

void tx_enable(){
    si5351.output_enable(TX_CLOCK,1);
    tx_state = 1;
}

void tx_disable(){
    si5351.output_enable(TX_CLOCK,0);
    tx_state = 0;
}

void tx(){
    digitalWrite(TX_RX_SWITCH, HIGH);
    digitalWrite(LED, HIGH);
    tx_relay_state = 1;
}

void rx(){
    digitalWrite(TX_RX_SWITCH, LOW);
    digitalWrite(LED, LOW);
    tx_relay_state = 0;
}

#define MIN_CHANNEL 1
#define MAX_CHANNEL 30


#ifdef USE_FLASH
// From https://docs.google.com/spreadsheets/d/1KP5XsAHPCD2FsUW5RoqCfCJYRt2o03q6RN2TroPgEKk/edit#gid=0
const prog_uint16_t channel_list[] =
#else
const uint16_t channel_list[] =
#endif
        {8986, 8990, 8993, 8996, 9000, 9003, 9006, 9010, 9013, 9016, 9020, 9023, 9026,
        9030, 9033, 9036, 9040, 9043, 9046, 9050, 9053, 9056, 9060, 9063, 9066, 9070,
        9073, 9076, 9080, 9083};

int set_channel(String input)
{
  unsigned long chan = 0;
  char* endptr;
  
  input.toCharArray(tempBuffer,10);
  
  chan = strtoul(tempBuffer,&endptr,10);
  // If strtoul fails to convert, *endptr contains the character which conversion failed on.
  // Otherwise, *endptr contains '\0'.
  if(*endptr != 0) return -1;



    if (chan < MIN_CHANNEL || chan > MAX_CHANNEL) {
        return 1;
    }

#ifdef USE_FLASH
    uint32_t rx = (uint32_t)pgm_read_word_near(channel_list + chan-1) * 1000;
#else
    uint32_t rx = (uint32_t)channel_list[chan-1] * 1000;
#endif
    uint32_t tx = rx * 3 + 1500;

    set_rx_freq(rx);
    set_tx_freq(tx);

    // Save settings
//    write_settings();

    Serial.print("CHAN,"); Serial.println(chan);
    return 0;
}

//int psk_transmit(String param1, String param2){
//  unsigned long baud_rate = 0;
//  char* endptr;
//  
//  param1.toCharArray(tempBuffer,10);
//  
//  baud_rate = strtoul(tempBuffer,&endptr,10);
//  // If strtoul fails to convert, *endptr contains the character which conversion failed on.
//  // Otherwise, *endptr contains '\0'.
//  if(*endptr != 0) return -1;
//
//    tx();
//    tx_enable();
//    if (!bpsk_start(baud_rate)){
//      tx_disable();
//      rx();
//        return 1;
//    }
//    delay(300); //  Short delay for RX sync to occur.
//    // Push string into ring buffer for transmission.
//    for(int i = 0; i<param2.length(); i++){
//      store_char(param2.charAt(i),&data_tx_buffer);
//    }
//    // Send an EOT control character, then a newline, to signify the end of the message.
//    store_char((char)4, &data_tx_buffer);
//    store_char('\n', &data_tx_buffer);
//    while(data_waiting(&data_tx_buffer)>0){}
//    delay(300);
//    bpsk_stop();
//    tx_disable();
//    rx();
//
//    return 0;
//}

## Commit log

2022-04-18 Lowpass and Bandpass Filters
2022-04-18 Create Schematics
2022-04-18 Schematics v1
    [Arduino and Si5354.kicad_sch, BandPass Filter.kicad_sch, LowPassFilter.kicad_sch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]
2022-04-19 Complete Schematic v3
    [Complet Schemativ v3.kicad_sch]
2022-04-19 Added bypass capacitors to our schematic
    [Complet Schemativ v3.kicad_sch]
2022-04-21 Added pull up resistors, bypass capacitors, split the gain between our amplifiers, and changes our bypass filter to 7-18 Mhz
    [Complet Schemativ v3.kicad_sch]
2022-04-25 New Complete Schematic Versions
    [Complet Schemativ v3.kicad_sch, Complete Schematic V4.kicad_pcb, Complete Schematic V4.kicad_sch]
2022-04-28 New Update
    [Complete Schematic V4.kicad_sch]
2022-04-28 Schematic with all footprints for checking and the parts lists with the links
    [Complete Schematic V4.kicad_sch]
2022-04-28 updated schematic
    [Complete Schematic V4.kicad_pcb, Complete Schematic V4.kicad_sch]
2022-04-28 PCB Design
    [Complete Schematic V4.kicad_pcb, Complete Schematic V4.kicad_sch]
2022-04-29 Final Schematic and PCB
    [Audio Jack.f3d, Audio Jack.step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]
2022-05-01 Final Changes before PCB sent out
    [Complete Schematic V4.kicad_pcb]
2022-05-02 Christian's PCB Work, But Josh's PCB Design is what we're using
    [Complete Schematic V4.csv, Complete Schematic V4.kicad_pcb, Complete Schematic V4.kicad_sch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]
2022-05-02 trying to update christian v3
    [Complete Schematic V4.kicad_sch]
2022-06-01 updated values
    [Complete Schematic V4.kicad_sch]
2022-06-02 new changes to orgnization
    [Complete Schematic V4.kicad_sch]
2022-06-02 offical changes is files we need
    [Complete Schematic V4.csv, Complete Schematic V4.xlsx]
2022-06-02 Organization Changes. Deleted files we don't use, and organized the rest into properly names files.
    [Arduino and Si5354.kicad_sch, BandPass Filter.kicad_sch, Complete Schematic V3.kicad_sch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]
2022-06-03 Created New Folders
    [Arduino and Si5354.kicad_sch, Audio Jack.f3d, Audio Jack.step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]
2022-06-03 Renamed Versions of our schematics
    [Complete Schematic V4-B_Cu.gbr, Complete Schematic V4-B_Mask.gbr, Complete Schematic V4-B_Silkscreen.gbr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]
2022-06-06 Updated V6 Board
    [Complete Schematic V6.kicad_pcb, Complete Schematic V6.kicad_sch, Complete Schematic V6backup.kicad_pcb]
2022-06-06 Addel Gerber, PDF, and Drill Files. Addes Pictures Folder
    [BandPass Filter.kicad_sch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]
2022-06-08 Merge branch 'main' of https://github.com/cwill713/Software-Defined-Radio into Christian_V4
    # Conflicts:
    # Schematic Files/Complete Schematic V4/Complete Schematic V4-backups/Complete Schematic V4-2022-04-28_000705.zip
    # Schematic Files/Complete Schematic V4/Complete Schematic V4-backups/Complete Schematic V4-2022-04-28_035923.zip
    # Schematic Files/Complete Schematic V4/Complete Schematic V4-backups/Complete Schematic V4-2022-04-28_040923.zip
    # Schematic Files/Complete Schematic V4/Complete Schematic V4-backups/Complete Schematic V4-2022-04-28_041923.zip
    # Schematic Files/Complete Schematic V4/Complete Schematic V4-backups/Complete Schematic V4-2022-04-28_042923.zip
    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
    [Arduino and Si5354.kicad_sch]

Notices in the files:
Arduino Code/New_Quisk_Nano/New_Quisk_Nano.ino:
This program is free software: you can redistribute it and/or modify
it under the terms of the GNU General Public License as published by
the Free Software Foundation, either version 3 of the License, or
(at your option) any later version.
